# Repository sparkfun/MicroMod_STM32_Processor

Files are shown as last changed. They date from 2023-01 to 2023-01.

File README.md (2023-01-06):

SparkFun STM32 MicroMod Processor
========================================

SparkFun STM32 MicroMod Processor

[*SparkFun STM32 MicroMod Processor v20 (21326)*](https://www.sparkfun.com/products/21326)

We've brought the power and precision of the STM32 Processor to the [SparkFun MicroMod ecosystem](https://www.sparkfun.com/micromod)! Please welcome the [MicroMod STM32 Processor Board](https://www.sparkfun.com/products/21326)! With the high-performance Arm® Cortex®-M4 32-bit RISC core, Flash memory up to 1 Mbyte, up to 192 Kbytes of SRAM, a memory protection unit (MPU), high-speed embedded memories, up to 4 Kbytes of backup SRAM, and an extensive range of enhanced I/Os and peripherals, this board is chock full of functionality. 

Repository Contents
-------------------

* **/Hardware** - Eagle design files (.brd, .sch)
* **/Production** - Production panel files (.brd)

Documentation
--------------
* **[Hookup Guide](https://learn.sparkfun.com/tutorials/micromod-stm32-processor-hookup-guide)** - Basic hookup guide for the MicroMod STM32 Processor Board.
* **[Getting Started with MicroMod](https://learn.sparkfun.com/tutorials/getting-started-with-micromod)** - A tutorial to help you get started with the MicroMod Ecosystem. 
* **[Designing with MicroMod](https://learn.sparkfun.com/tutorials/designing-with-micromod)** - A tutorial to walk you through the specs of the MicroMod processor and carrier board as well as the basics of incorporating the MicroMod form factor into your own PCB designs.

License Information
-------------------

This product is _**open source**_! 

Please review the LICENSE.md file for license information. 

If you have any questions or concerns on licensing, please contact technical support on our [SparkFun forums](https://forum.sparkfun.com/viewforum.php?f=152).

Distributed as-is; no warranty is given.

- Your friends at SparkFun.

_<COLLABORATION CREDIT>_

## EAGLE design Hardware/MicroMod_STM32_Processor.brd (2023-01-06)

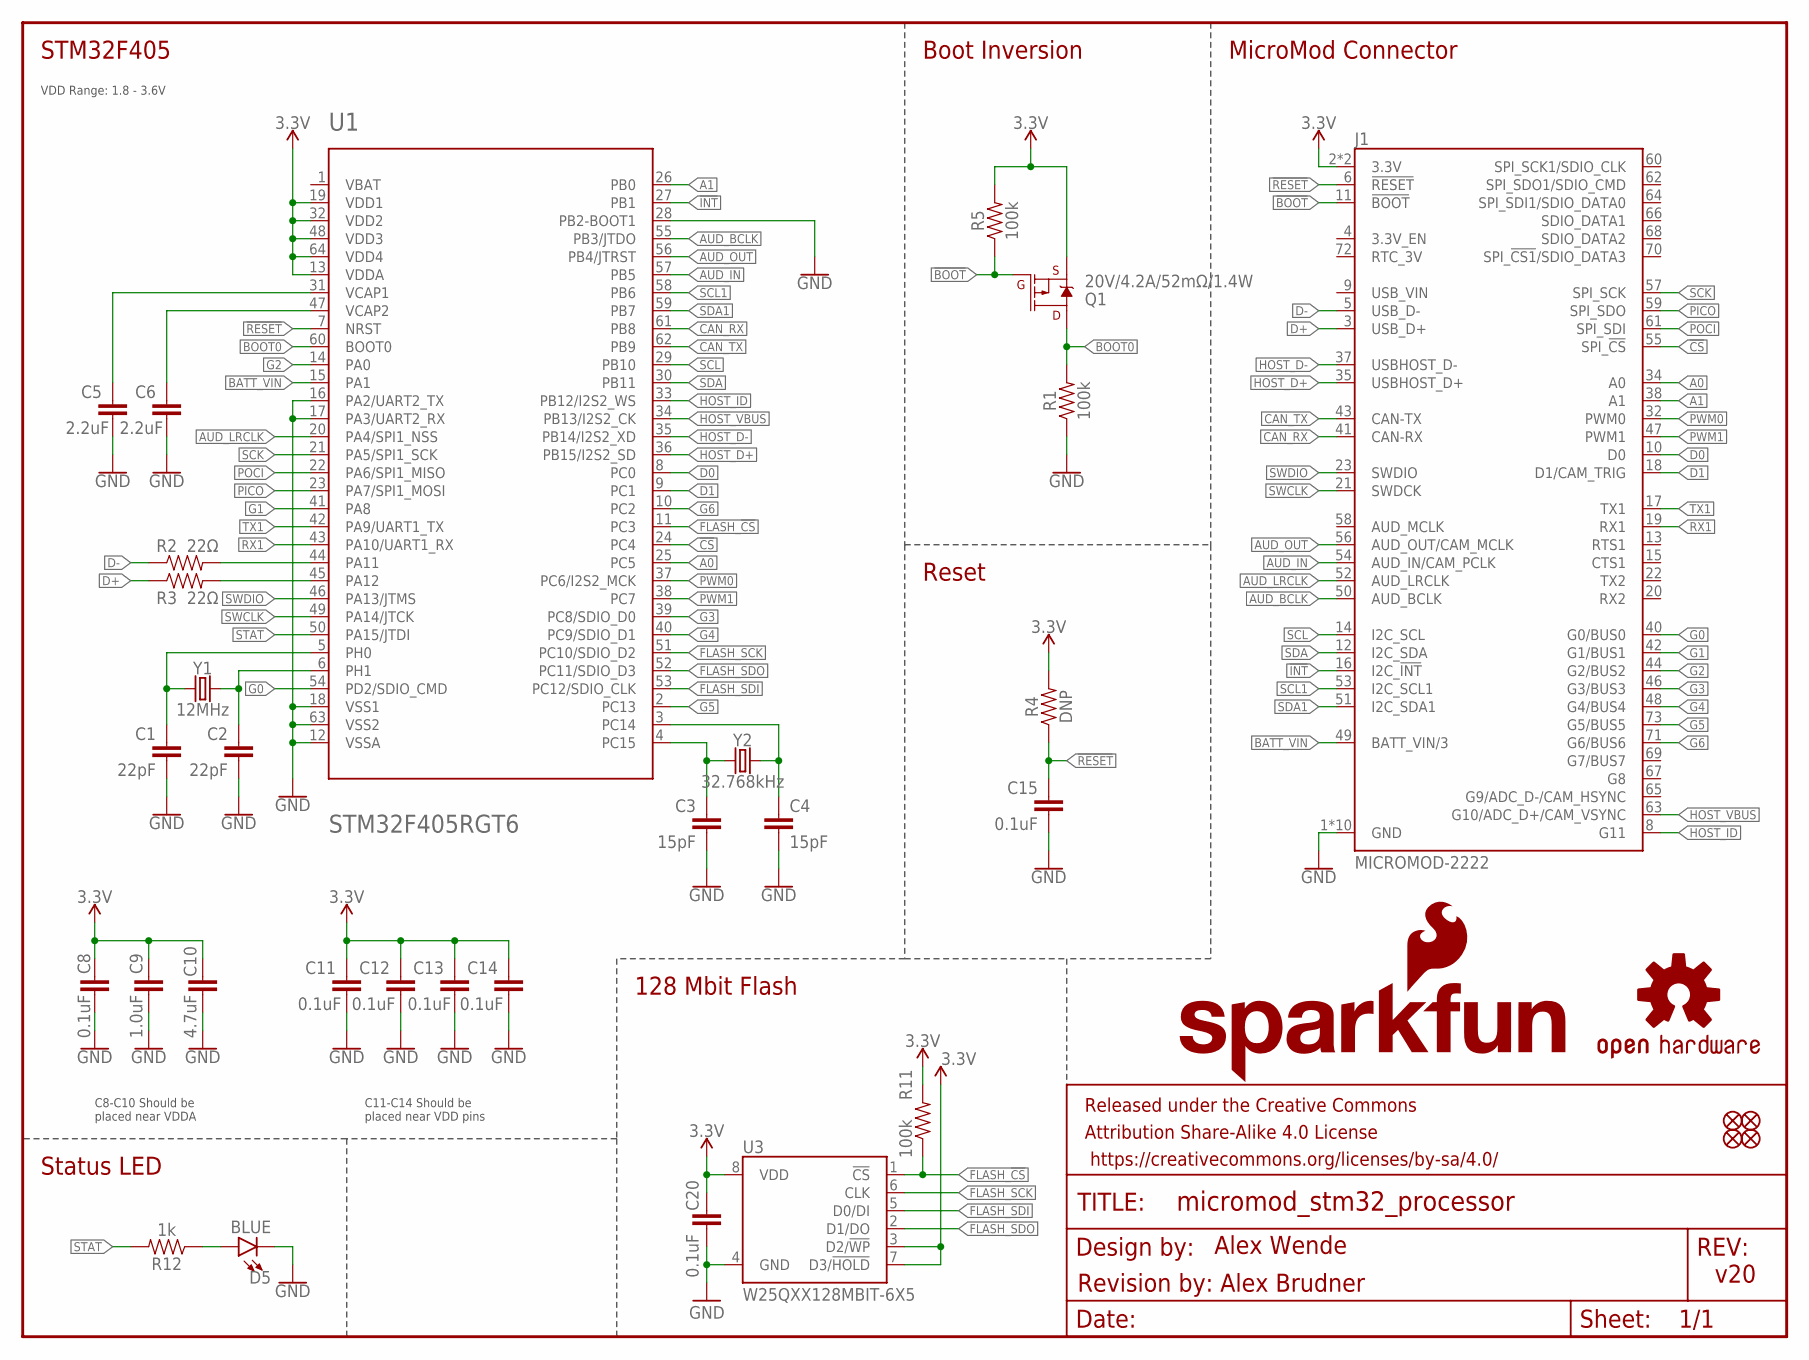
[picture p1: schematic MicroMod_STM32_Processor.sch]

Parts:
C1, C2: 22pF; 0402-TIGHT
C3, C4: 15pF; 0402-TIGHT
C5, C6: 2.2uF; 0402-TIGHT
C8, C11, C12, C13, C14, C15, C20: 0.1uF; 0402-TIGHT
C9: 1.0uF; 0402-TIGHT
C10: 4.7uF; 0402-TIGHT
D5: BLUE; LED-0603
FD1, FD2, FD3, FD4: FIDUCIALUFIDUCIAL; FIDUCIAL-MICRO
FRAME1: FRAME-LETTER; CREATIVE_COMMONS
J1: MICROMOD-2222; M.2-CARD-E-22
LOGO2: OSHW-LOGOS; OSHW-LOGO-S
LOGO3: SFE_LOGO_NAME_FLAME.1_INCH; SFE_LOGO_NAME_FLAME_.1
Q1: 20V/4.2A/52mΩ/1.4W; SOT23-3
R1, R5, R11: 100k; 0402-TIGHT
R2, R3: 22Ω; 0402-TIGHT
R4: DNP; 0402-TIGHT_NO_CREAM
R12: 1k; 0402-TIGHT
U1: STM32F405RGT6; TQFP64
U3: W25QXX128MBIT-6X5; WSON-8-6X5
Y1: 12MHz; CRYSTAL-SMD-5X3.2-4PAD
Y2: 32.768kHz; CRYSTAL-SMD-3.2X1.5MM

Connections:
3.3V: C8.1, C9.1, C10.1, C11.1, C12.1, C13.1, C14.1, C20.1, J1.2 (3.3V), J1.74 (3.3V), Q1.2 (S), R4.2, R5.2, R11.2, U1.13 (VDDA), U1.19 (VDD1), U1.32 (VDD2), U1.48 (VDD3), U1.64 (VDD4), U3.3 (D2/!WP!), U3.7 (D3/!HOLD!), U3.8 (VDD)
!BOOT: J1.11 (!BOOT!), Q1.1 (G), R5.1
!CS: J1.55 (SPI_!CS!), U1.24 (PC4)
!INT: J1.16 (I2C_!INT!), U1.27 (PB1)
!RESET: C15.1, J1.6 (!RESET!), R4.1, U1.7 (NRST)
A0: J1.34 (A0), U1.25 (PC5)
A1: J1.38 (A1), U1.26 (PB0)
AUD_BCLK: J1.50 (AUD_BCLK), U1.55 (PB3/JTDO)
AUD_IN: J1.54 (AUD_IN/CAM_PCLK), U1.57 (PB5)
AUD_LRCLK: J1.52 (AUD_LRCLK), U1.20 (PA4/SPI1_NSS)
AUD_OUT: J1.56 (AUD_OUT/CAM_MCLK), U1.56 (PB4/JTRST)
BATT_VIN: J1.49 (BATT_VIN/3), U1.15 (PA1)
BOOT0: Q1.3 (D), R1.2, U1.60 (BOOT0)
CAN_RX: J1.41 (CAN-RX), U1.61 (PB8)
CAN_TX: J1.43 (CAN-TX), U1.62 (PB9)
D0: J1.10 (D0), U1.8 (PC0)
D1: J1.18 (D1/CAM_TRIG), U1.9 (PC1)
D+: J1.3 (USB_D+), R3.1
D-: J1.5 (USB_D-), R2.1
FLASH_!CS: R11.1, U1.11 (PC3), U3.1 (!CS!)
FLASH_SCK: U1.51 (PC10/SDIO_D2), U3.6 (CLK)
FLASH_SDI: U1.53 (PC12/SDIO_CLK), U3.5 (D0/DI)
FLASH_SDO: U1.52 (PC11/SDIO_D3), U3.2 (D1/DO)
G0: J1.40 (G0/BUS0), U1.54 (PD2/SDIO_CMD)
G1: J1.42 (G1/BUS1), U1.41 (PA8)
G2: J1.44 (G2/BUS2), U1.14 (PA0)
G3: J1.46 (G3/BUS3), U1.39 (PC8/SDIO_D0)
G4: J1.48 (G4/BUS4), U1.40 (PC9/SDIO_D1)
G5: J1.73 (G5/BUS5), U1.2 (PC13)
G6: J1.71 (G6/BUS6), U1.10 (PC2)
GND: C1.2, C2.2, C3.2, C4.2, C5.2, C6.2, C8.2, C9.2, C10.2, C11.2, C12.2, C13.2, C14.2, C15.2, C20.2, D5.C, J1.1 (GND), J1.7 (GND), J1.33 (GND), J1.36 (GND), J1.39 (GND), J1.45 (GND), J1.75 (GND), J1.GND1 (GND), J1.GND2 (GND), J1.GND3 (GND), R1.1, U1.12 (VSSA), U1.16 (PA2/UART2_TX), U1.17 (PA3/UART2_RX), U1.18 (VSS1), U1.28 (PB2-BOOT1), U1.63 (VSS2), U3.4 (GND)
HOST_D+: J1.35 (USBHOST_D+), U1.36 (PB15/I2S2_SD)
HOST_D-: J1.37 (USBHOST_D-), U1.35 (PB14/I2S2_XD)
HOST_ID: J1.8 (G11), U1.33 (PB12/I2S2_WS)
HOST_VBUS: J1.63 (G10/ADC_D+/CAM_VSYNC), U1.34 (PB13/I2S2_CK)
unnamed: D5.A, R12.1
unnamed: R2.2, U1.44 (PA11)
unnamed: R3.2, U1.45 (PA12)
unnamed: C4.1, U1.3 (PC14), Y2.P$2 (2)
unnamed: C3.1, U1.4 (PC15), Y2.P$1 (1)
unnamed: C2.1, U1.6 (PH1), Y1.3 (2)
unnamed: C1.1, U1.5 (PH0), Y1.1
unnamed: C6.1, U1.47 (VCAP2)
unnamed: C5.1, U1.31 (VCAP1)
PICO: J1.59 (SPI_SDO), U1.23 (PA7/SPI1_MOSI)
POCI: J1.61 (SPI_SDI), U1.22 (PA6/SPI1_MISO)
PWM0: J1.32 (PWM0), U1.37 (PC6/I2S2_MCK)
PWM1: J1.47 (PWM1), U1.38 (PC7)
RX1: J1.19 (RX1), U1.43 (PA10/UART1_RX)
SCK: J1.57 (SPI_SCK), U1.21 (PA5/SPI1_SCK)
SCL: J1.14 (I2C_SCL), U1.29 (PB10)
SCL1: J1.53 (I2C_SCL1), U1.58 (PB6)
SDA: J1.12 (I2C_SDA), U1.30 (PB11)
SDA1: J1.51 (I2C_SDA1), U1.59 (PB7)
STAT: R12.2, U1.50 (PA15/JTDI)
SWCLK: J1.21 (SWDCK), U1.49 (PA14/JTCK)
SWDIO: J1.23 (SWDIO), U1.46 (PA13/JTMS)
TX1: J1.17 (TX1), U1.42 (PA9/UART1_TX)

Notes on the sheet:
128 Mbit Flash
Status LED
C11-C14 Should be placed near VDD pins
C8-C10 Should be placed near VDDA
Boot Inversion
Reset
MicroMod Connector
STM32F405
v20
Alex Wende
VDD Range: 1.8 - 3.6V
Revision by: Alex Brudner

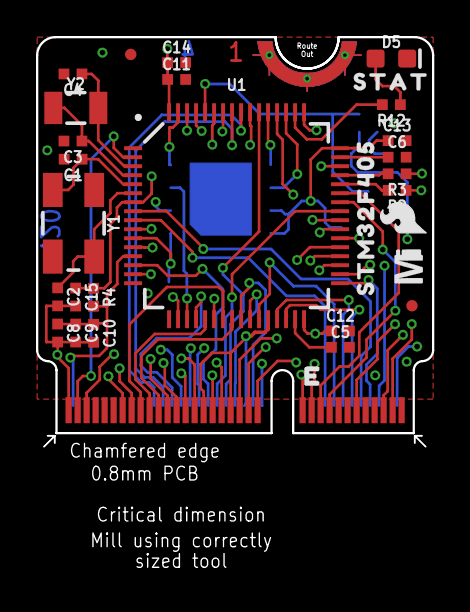
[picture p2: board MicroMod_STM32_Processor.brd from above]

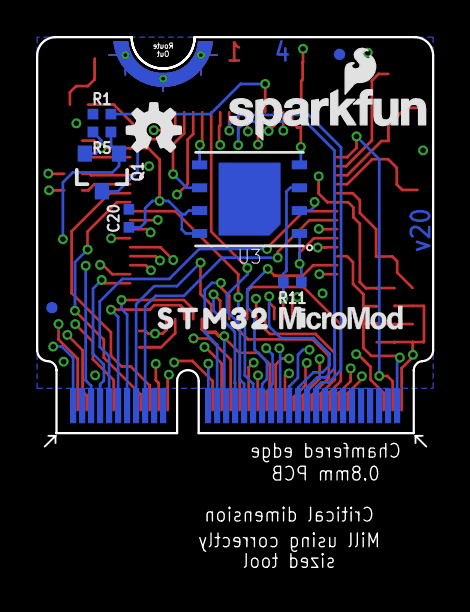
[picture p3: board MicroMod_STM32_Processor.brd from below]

Board: 4 copper layers, 22.0 x 22.8 mm, 43 parts (12 on the bottom side), 58 nets.

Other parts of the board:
U$1: STAT0
U$2: STM320
U$3: MICROMOD_MI_LOGO_.35
U$4: STM32F4050
U$5: MICROMOD_LOGO_.3
U$6: SFE_LOGO_FLAME_.1
U$7: PRODUCTION_INSTRUCTIONS

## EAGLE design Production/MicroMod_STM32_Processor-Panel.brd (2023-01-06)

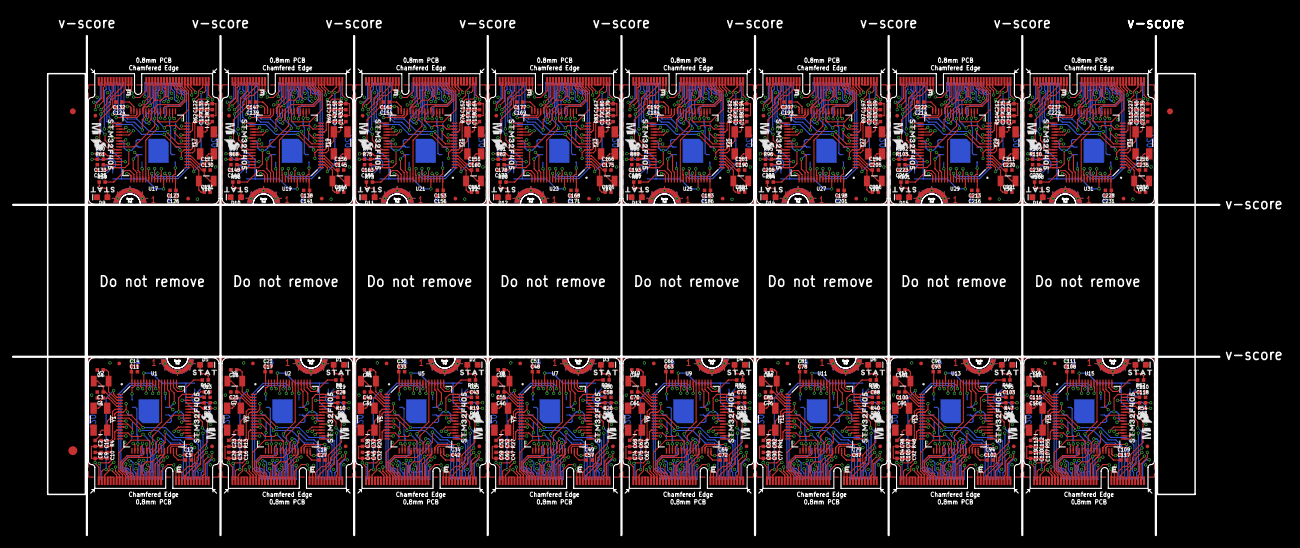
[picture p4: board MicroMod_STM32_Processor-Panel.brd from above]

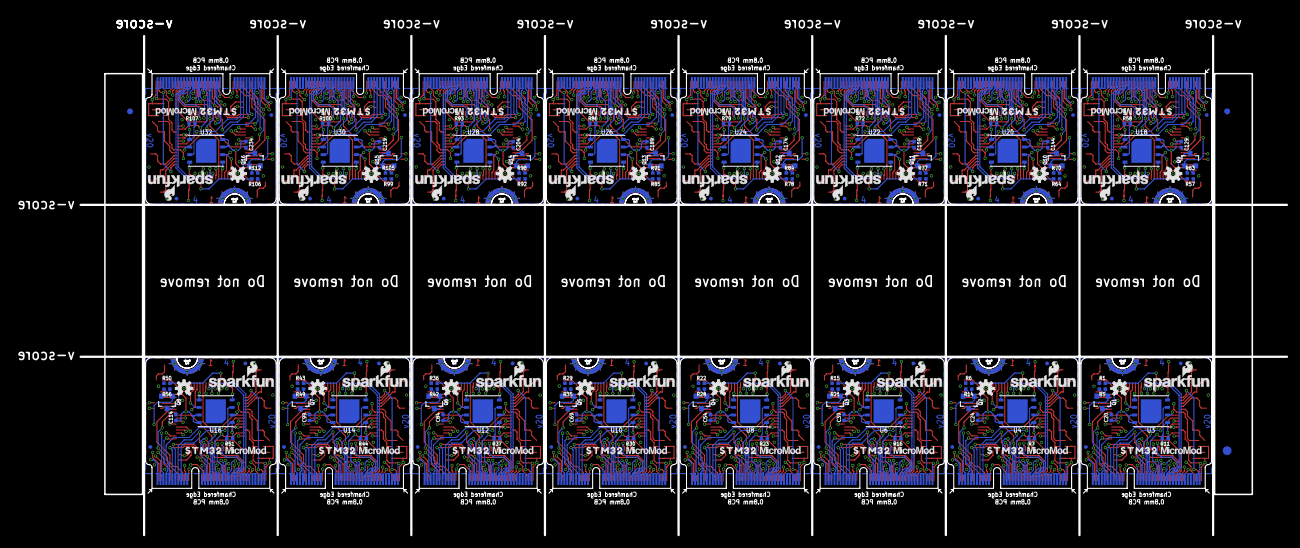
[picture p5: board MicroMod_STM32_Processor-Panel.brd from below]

Board: 4 copper layers, 203.2 x 84.1 mm, 662 parts (195 on the bottom side), 928 nets.

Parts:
C1, C2, C7, C23, C31, C38, C46, C53, C61, C68, C76, C83, C91, C98, C106, C113, C121, C128, C136, C143, C151, C158, C166, C173, C181, C188, C196, C203, C211, C218, C226, C233: 22pF; 0402-TIGHT
C3, C4, C25, C26, C40, C41, C55, C56, C70, C71, C85, C86, C100, C101, C115, C116, C130, C131, C145, C146, C160, C161, C175, C176, C190, C191, C205, C206, C220, C221, C235, C236: 15pF; 0402-TIGHT
C5, C6, C27, C28, C42, C43, C57, C58, C72, C73, C87, C88, C102, C103, C117, C118, C132, C133, C147, C148, C162, C163, C177, C178, C192, C193, C207, C208, C222, C223, C237, C238: 2.2uF; 0402-TIGHT
C8, C11, C12, C13, C14, C15, C17, C18, C19, C20, C21, C22, C24, C29, C33, C34, C35, C36, C37, C39, C44, C48, C49, C50, C51, C52, C54, C59, C63, C64, C65, C66, C67, C69, C74, C78, C79, C80, C81, C82, C84, C89, C93, C94, C95, C96, C97, C99, C104, C108, C109, C110, C111, C112, C114, C119, C123, C124, C125, C126, C127, C129, C134, C138, C139, C140, C141, C142, C144, C149, C153, C154, C155, C156, C157, C159, C164, C168, C169, C170, C171, C172, C174, C179, C183, C184, C185, C186, C187, C189, C194, C198, C199, C200, C201, C202, C204, C209, C213, C214, C215, C216, C217, C219, C224, C228, C229, C230, C231, C232, C234, C239: 0.1uF; 0402-TIGHT
C9, C30, C45, C60, C75, C90, C105, C120, C135, C150, C165, C180, C195, C210, C225, C240: 1.0uF; 0402-TIGHT
C10, C16, C32, C47, C62, C77, C92, C107, C122, C137, C152, C167, C182, C197, C212, C227: 4.7uF; 0402-TIGHT
D1, D2, D3, D4, D5, D6, D7, D8, D9, D10, D11, D12, D13, D14, D15, D16: BLUE; LED-0603
E$1, E$2, E$3, E$4: FIDUCIAL-1X2
E$5, E$6: FIDUCIAL-1.5X3
FD1, FD2, FD3, FD4, FD5, FD6, FD7, FD8, FD9, FD10, FD11, FD12, FD13, FD14, FD15, FD16, FD17, FD18, FD19, FD20, FD21, FD22, FD23, FD24, FD25, FD26, FD27, FD28, FD29, FD30, FD31, FD32, FD33, FD34, FD35, FD36, FD37, FD38, FD39, FD40, FD41, FD42, FD43, FD44, FD45, FD46, FD47, FD48, FD49, FD50, FD51, FD52, FD53, FD54, FD55, FD56, FD57, FD58, FD59, FD60, FD61, FD62, FD63, FD64: FIDUCIALUFIDUCIAL; FIDUCIAL-MICRO
J1, J2, J3, J4, J5, J6, J7, J8, J9, J10, J11, J12, J13, J14, J15, J16: MICROMOD-2222; M.2-CARD-E-22
LOGO1, LOGO2, LOGO5, LOGO7, LOGO9, LOGO11, LOGO13, LOGO15, LOGO17, LOGO19, LOGO21, LOGO23, LOGO25, LOGO27, LOGO29, LOGO31: OSHW-LOGOS; OSHW-LOGO-S
LOGO3, LOGO4, LOGO6, LOGO8, LOGO10, LOGO12, LOGO14, LOGO16, LOGO18, LOGO20, LOGO22, LOGO24, LOGO26, LOGO28, LOGO30, LOGO32: SFE_LOGO_NAME_FLAME.1_INCH; SFE_LOGO_NAME_FLAME_.1
Q1, Q2, Q3, Q4, Q5, Q6, Q7, Q8, Q9, Q10, Q11, Q12, Q13, Q14, Q15, Q16: SOT23-3
R1, R5, R6, R7, R11, R14, R15, R16, R21, R22, R23, R28, R29, R30, R35, R36, R37, R42, R43, R44, R49, R50, R51, R56, R57, R58, R63, R64, R65, R70, R71, R72, R77, R78, R79, R84, R85, R86, R91, R92, R93, R98, R99, R100, R105, R106, R107, R112: 100k; 0402-TIGHT
R2, R3, R9, R10, R18, R19, R25, R26, R32, R33, R39, R40, R46, R47, R53, R54, R60, R61, R67, R68, R74, R75, R81, R82, R88, R89, R95, R96, R102, R103, R109, R110: 22; 0402-TIGHT
R4, R13, R20, R27, R34, R41, R48, R55, R62, R69, R76, R83, R90, R97, R104, R111: 5.1k; 0402-TIGHT
R8, R12, R17, R24, R31, R38, R45, R52, R59, R66, R73, R80, R87, R94, R101, R108: 1k; 0402-TIGHT
U1, U2, U5, U7, U9, U11, U13, U15, U17, U19, U21, U23, U25, U27, U29, U31: STM32F405RGT6; TQFP64
U3, U4, U6, U8, U10, U12, U14, U16, U18, U20, U22, U24, U26, U28, U30, U32: W25QXX128MBIT-6X5; WSON-8-6X5
U$1, U$7, U$13, U$19, U$25, U$31, U$37, U$43, U$49, U$55, U$61, U$67, U$73, U$79, U$85, U$91: STAT0
U$2, U$8, U$14, U$20, U$26, U$32, U$38, U$44, U$50, U$56, U$62, U$68, U$74, U$80, U$86, U$92: STM320
U$3, U$9, U$15, U$21, U$27, U$33, U$39, U$45, U$51, U$57, U$63, U$69, U$75, U$81, U$87, U$93: MICROMOD_MI_LOGO_.35
U$4, U$10, U$16, U$22, U$28, U$34, U$40, U$46, U$52, U$58, U$64, U$70, U$76, U$82, U$88, U$94: STM32F4050
U$5, U$11, U$17, U$23, U$29, U$35, U$41, U$47, U$53, U$59, U$65, U$71, U$77, U$83, U$89, U$95: MICROMOD_LOGO_.3
U$6, U$12, U$18, U$24, U$30, U$36, U$42, U$48, U$54, U$60, U$66, U$72, U$78, U$84, U$90, U$96: SFE_LOGO_FLAME_.1
Y1, Y3, Y5, Y7, Y9, Y11, Y13, Y15, Y17, Y19, Y21, Y23, Y25, Y27, Y29, Y31: 12MHz; CRYSTAL-SMD-5X3.2-4PAD
Y2, Y4, Y6, Y8, Y10, Y12, Y14, Y16, Y18, Y20, Y22, Y24, Y26, Y28, Y30, Y32: 32.768kHz; CRYSTAL-SMD-3.2X1.5MM

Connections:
3.3V: C8.1, C9.1, C10.1, C11.1, C12.1, C13.1, C14.1, C20.1, J1.2, J1.74, Q1.2, R4.2, R5.2, R11.2, U1.13, U1.19, U1.32, U1.48, U1.64, U3.3, U3.7, U3.8
3.3V1: C16.1, C17.1, C18.1, C19.1, C21.1, C24.1, C29.1, C30.1, J2.2, J2.74, Q2.2, R7.2, R13.2, R14.2, U2.13, U2.19, U2.32, U2.48, U2.64, U4.3, U4.7, U4.8
3.3V2: C32.1, C33.1, C34.1, C35.1, C36.1, C39.1, C44.1, C45.1, J3.2, J3.74, Q3.2, R16.2, R20.2, R21.2, U5.13, U5.19, U5.32, U5.48, U5.64, U6.3, U6.7, U6.8
3.3V3: C47.1, C48.1, C49.1, C50.1, C51.1, C54.1, C59.1, C60.1, J4.2, J4.74, Q4.2, R23.2, R27.2, R28.2, U7.13, U7.19, U7.32, U7.48, U7.64, U8.3, U8.7, U8.8
3.3V4: C62.1, C63.1, C64.1, C65.1, C66.1, C69.1, C74.1, C75.1, J5.2, J5.74, Q5.2, R30.2, R34.2, R35.2, U9.13, U9.19, U9.32, U9.48, U9.64, U10.3, U10.7, U10.8
3.3V5: C77.1, C78.1, C79.1, C80.1, C81.1, C84.1, C89.1, C90.1, J6.2, J6.74, Q6.2, R37.2, R41.2, R42.2, U11.13, U11.19, U11.32, U11.48, U11.64, U12.3, U12.7, U12.8
3.3V6: C92.1, C93.1, C94.1, C95.1, C96.1, C99.1, C104.1, C105.1, J7.2, J7.74, Q7.2, R44.2, R48.2, R49.2, U13.13, U13.19, U13.32, U13.48, U13.64, U14.3, U14.7, U14.8
3.3V7: C107.1, C108.1, C109.1, C110.1, C111.1, C114.1, C119.1, C120.1, J8.2, J8.74, Q8.2, R51.2, R55.2, R56.2, U15.13, U15.19, U15.32, U15.48, U15.64, U16.3, U16.7, U16.8
3.3V8: C122.1, C123.1, C124.1, C125.1, C126.1, C129.1, C134.1, C135.1, J9.2, J9.74, Q9.2, R58.2, R62.2, R63.2, U17.13, U17.19, U17.32, U17.48, U17.64, U18.3, U18.7, U18.8
3.3V9: C137.1, C138.1, C139.1, C140.1, C141.1, C144.1, C149.1, C150.1, J10.2, J10.74, Q10.2, R65.2, R69.2, R70.2, U19.13, U19.19, U19.32, U19.48, U19.64, U20.3, U20.7, U20.8
3.3V10: C152.1, C153.1, C154.1, C155.1, C156.1, C159.1, C164.1, C165.1, J11.2, J11.74, Q11.2, R72.2, R76.2, R77.2, U21.13, U21.19, U21.32, U21.48, U21.64, U22.3, U22.7, U22.8
3.3V11: C167.1, C168.1, C169.1, C170.1, C171.1, C174.1, C179.1, C180.1, J12.2, J12.74, Q12.2, R79.2, R83.2, R84.2, U23.13, U23.19, U23.32, U23.48, U23.64, U24.3, U24.7, U24.8
3.3V12: C182.1, C183.1, C184.1, C185.1, C186.1, C189.1, C194.1, C195.1, J13.2, J13.74, Q13.2, R86.2, R90.2, R91.2, U25.13, U25.19, U25.32, U25.48, U25.64, U26.3, U26.7, U26.8
3.3V13: C197.1, C198.1, C199.1, C200.1, C201.1, C204.1, C209.1, C210.1, J14.2, J14.74, Q14.2, R93.2, R97.2, R98.2, U27.13, U27.19, U27.32, U27.48, U27.64, U28.3, U28.7, U28.8
3.3V14: C212.1, C213.1, C214.1, C215.1, C216.1, C219.1, C224.1, C225.1, J15.2, J15.74, Q15.2, R100.2, R104.2, R105.2, U29.13, U29.19, U29.32, U29.48, U29.64, U30.3, U30.7, U30.8
3.3V15: C227.1, C228.1, C229.1, C230.1, C231.1, C234.1, C239.1, C240.1, J16.2, J16.74, Q16.2, R107.2, R111.2, R112.2, U31.13, U31.19, U31.32, U31.48, U31.64, U32.3, U32.7, U32.8
!BOOT: J1.11, Q1.1, R5.1
!BOOT1: J2.11, Q2.1, R14.1
!BOOT2: J3.11, Q3.1, R21.1
!BOOT3: J4.11, Q4.1, R28.1
!BOOT4: J5.11, Q5.1, R35.1
!BOOT5: J6.11, Q6.1, R42.1
!BOOT6: J7.11, Q7.1, R49.1
!BOOT7: J8.11, Q8.1, R56.1
!BOOT8: J9.11, Q9.1, R63.1
!BOOT9: J10.11, Q10.1, R70.1
!BOOT10: J11.11, Q11.1, R77.1
!BOOT11: J12.11, Q12.1, R84.1
!BOOT12: J13.11, Q13.1, R91.1
!BOOT13: J14.11, Q14.1, R98.1
!BOOT14: J15.11, Q15.1, R105.1
!BOOT15: J16.11, Q16.1, R112.1
!CS: J1.55, U1.24
!CS1: J2.55, U2.24
!CS2: J3.55, U5.24
!CS3: J4.55, U7.24
!CS4: J5.55, U9.24
!CS5: J6.55, U11.24
!CS6: J7.55, U13.24
!CS7: J8.55, U15.24
!CS8: J9.55, U17.24
!CS9: J10.55, U19.24
!CS10: J11.55, U21.24
!CS11: J12.55, U23.24
!CS12: J13.55, U25.24
!CS13: J14.55, U27.24
!CS14: J15.55, U29.24
!CS15: J16.55, U31.24
!INT: J1.16, U1.27
!INT1: J2.16, U2.27
!INT2: J3.16, U5.27
!INT3: J4.16, U7.27
!INT4: J5.16, U9.27
!INT5: J6.16, U11.27
!INT6: J7.16, U13.27
!INT7: J8.16, U15.27
!INT8: J9.16, U17.27
!INT9: J10.16, U19.27
!INT10: J11.16, U21.27
!INT11: J12.16, U23.27
!INT12: J13.16, U25.27
!INT13: J14.16, U27.27
!INT14: J15.16, U29.27
!INT15: J16.16, U31.27
!RESET: C15.1, J1.6, R4.1, U1.7
!RESET1: C22.1, J2.6, R13.1, U2.7
!RESET2: C37.1, J3.6, R20.1, U5.7
!RESET3: C52.1, J4.6, R27.1, U7.7
!RESET4: C67.1, J5.6, R34.1, U9.7
!RESET5: C82.1, J6.6, R41.1, U11.7
!RESET6: C97.1, J7.6, R48.1, U13.7
!RESET7: C112.1, J8.6, R55.1, U15.7
!RESET8: C127.1, J9.6, R62.1, U17.7
!RESET9: C142.1, J10.6, R69.1, U19.7
!RESET10: C157.1, J11.6, R76.1, U21.7
!RESET11: C172.1, J12.6, R83.1, U23.7
!RESET12: C187.1, J13.6, R90.1, U25.7
!RESET13: C202.1, J14.6, R97.1, U27.7
!RESET14: C217.1, J15.6, R104.1, U29.7
!RESET15: C232.1, J16.6, R111.1, U31.7
A0: J1.34, U1.25
A1: J1.38, U1.26
A2: J2.34, U2.25
A3: J2.38, U2.26
A4: J3.34, U5.25
A5: J3.38, U5.26
A6: J4.34, U7.25
A7: J4.38, U7.26
A8: J5.34, U9.25
A9: J5.38, U9.26
A10: J6.34, U11.25
A11: J6.38, U11.26
A12: J7.34, U13.25
A13: J7.38, U13.26
A14: J8.34, U15.25
A15: J8.38, U15.26
A16: J9.34, U17.25
A17: J9.38, U17.26
A18: J10.34, U19.25
A19: J10.38, U19.26
A20: J11.34, U21.25
A21: J11.38, U21.26
A22: J12.34, U23.25
A23: J12.38, U23.26
A24: J13.34, U25.25
A25: J13.38, U25.26
A26: J14.34, U27.25
A27: J14.38, U27.26
A28: J15.34, U29.25
A29: J15.38, U29.26
A30: J16.34, U31.25
A31: J16.38, U31.26
AUD_BCLK: J1.50, U1.55
AUD_BCLK1: J2.50, U2.55
AUD_BCLK2: J3.50, U5.55
AUD_BCLK3: J4.50, U7.55
AUD_BCLK4: J5.50, U9.55
AUD_BCLK5: J6.50, U11.55
AUD_BCLK6: J7.50, U13.55
AUD_BCLK7: J8.50, U15.55
AUD_BCLK8: J9.50, U17.55
AUD_BCLK9: J10.50, U19.55
AUD_BCLK10: J11.50, U21.55
AUD_BCLK11: J12.50, U23.55
AUD_BCLK12: J13.50, U25.55
AUD_BCLK13: J14.50, U27.55
AUD_BCLK14: J15.50, U29.55
AUD_BCLK15: J16.50, U31.55
AUD_IN: J1.54, U1.57
AUD_IN1: J2.54, U2.57
AUD_IN2: J3.54, U5.57
AUD_IN3: J4.54, U7.57
AUD_IN4: J5.54, U9.57
AUD_IN5: J6.54, U11.57
AUD_IN6: J7.54, U13.57
AUD_IN7: J8.54, U15.57
AUD_IN8: J9.54, U17.57
AUD_IN9: J10.54, U19.57
AUD_IN10: J11.54, U21.57
AUD_IN11: J12.54, U23.57
AUD_IN12: J13.54, U25.57
AUD_IN13: J14.54, U27.57
AUD_IN14: J15.54, U29.57
AUD_IN15: J16.54, U31.57
AUD_LRCLK: J1.52, U1.20
AUD_LRCLK1: J2.52, U2.20
AUD_LRCLK2: J3.52, U5.20
AUD_LRCLK3: J4.52, U7.20
AUD_LRCLK4: J5.52, U9.20
AUD_LRCLK5: J6.52, U11.20
AUD_LRCLK6: J7.52, U13.20
AUD_LRCLK7: J8.52, U15.20
AUD_LRCLK8: J9.52, U17.20
AUD_LRCLK9: J10.52, U19.20
AUD_LRCLK10: J11.52, U21.20
AUD_LRCLK11: J12.52, U23.20
AUD_LRCLK12: J13.52, U25.20
AUD_LRCLK13: J14.52, U27.20
AUD_LRCLK14: J15.52, U29.20
AUD_LRCLK15: J16.52, U31.20
AUD_OUT: J1.56, U1.56
AUD_OUT1: J2.56, U2.56
AUD_OUT2: J3.56, U5.56
AUD_OUT3: J4.56, U7.56
AUD_OUT4: J5.56, U9.56
AUD_OUT5: J6.56, U11.56
AUD_OUT6: J7.56, U13.56
AUD_OUT7: J8.56, U15.56
AUD_OUT8: J9.56, U17.56
AUD_OUT9: J10.56, U19.56
AUD_OUT10: J11.56, U21.56
AUD_OUT11: J12.56, U23.56
AUD_OUT12: J13.56, U25.56
AUD_OUT13: J14.56, U27.56
AUD_OUT14: J15.56, U29.56
AUD_OUT15: J16.56, U31.56
BATT_VIN: J1.49, U1.15
BATT_VIN1: J2.49, U2.15
BATT_VIN2: J3.49, U5.15
BATT_VIN3: J4.49, U7.15
BATT_VIN4: J5.49, U9.15
BATT_VIN5: J6.49, U11.15
BATT_VIN6: J7.49, U13.15
BATT_VIN7: J8.49, U15.15
BATT_VIN8: J9.49, U17.15
BATT_VIN9: J10.49, U19.15
BATT_VIN10: J11.49, U21.15
BATT_VIN11: J12.49, U23.15
BATT_VIN12: J13.49, U25.15
BATT_VIN13: J14.49, U27.15
BATT_VIN14: J15.49, U29.15
BATT_VIN15: J16.49, U31.15
BOOT0: Q1.3, R1.2, U1.60
BOOT1: Q2.3, R6.2, U2.60
BOOT2: Q3.3, R15.2, U5.60
BOOT3: Q4.3, R22.2, U7.60
BOOT4: Q5.3, R29.2, U9.60
BOOT5: Q6.3, R36.2, U11.60
BOOT6: Q7.3, R43.2, U13.60
BOOT7: Q8.3, R50.2, U15.60
BOOT8: Q9.3, R57.2, U17.60
BOOT9: Q10.3, R64.2, U19.60
BOOT10: Q11.3, R71.2, U21.60
BOOT11: Q12.3, R78.2, U23.60
BOOT12: Q13.3, R85.2, U25.60
BOOT13: Q14.3, R92.2, U27.60
BOOT14: Q15.3, R99.2, U29.60
BOOT15: Q16.3, R106.2, U31.60
CAN_RX: J1.41, U1.61
CAN_RX1: J2.41, U2.61
CAN_RX2: J3.41, U5.61
CAN_RX3: J4.41, U7.61
CAN_RX4: J5.41, U9.61
CAN_RX5: J6.41, U11.61
CAN_RX6: J7.41, U13.61
CAN_RX7: J8.41, U15.61
CAN_RX8: J9.41, U17.61
CAN_RX9: J10.41, U19.61
CAN_RX10: J11.41, U21.61
CAN_RX11: J12.41, U23.61
CAN_RX12: J13.41, U25.61
CAN_RX13: J14.41, U27.61
CAN_RX14: J15.41, U29.61
CAN_RX15: J16.41, U31.61
CAN_TX: J1.43, U1.62
CAN_TX1: J2.43, U2.62
CAN_TX2: J3.43, U5.62
CAN_TX3: J4.43, U7.62
CAN_TX4: J5.43, U9.62
CAN_TX5: J6.43, U11.62
CAN_TX6: J7.43, U13.62
CAN_TX7: J8.43, U15.62
CAN_TX8: J9.43, U17.62
CAN_TX9: J10.43, U19.62
CAN_TX10: J11.43, U21.62
CAN_TX11: J12.43, U23.62
CAN_TX12: J13.43, U25.62
CAN_TX13: J14.43, U27.62
CAN_TX14: J15.43, U29.62
CAN_TX15: J16.43, U31.62
D0: J1.10, U1.8
D1: J1.18, U1.9
D2: J2.10, U2.8
D3: J2.18, U2.9
D4: J3.10, U5.8
D5: J3.18, U5.9
D6: J4.10, U7.8
D7: J4.18, U7.9
D8: J5.10, U9.8
D9: J5.18, U9.9
D10: J6.10, U11.8
D11: J6.18, U11.9
D12: J7.10, U13.8
D13: J7.18, U13.9
D14: J8.10, U15.8
D15: J8.18, U15.9
D16: J9.10, U17.8
D17: J9.18, U17.9
D18: J10.10, U19.8
D19: J10.18, U19.9
D20: J11.10, U21.8
D21: J11.18, U21.9
D22: J12.10, U23.8
D23: J12.18, U23.9
D24: J13.10, U25.8
D25: J13.18, U25.9
D26: J14.10, U27.8
D27: J14.18, U27.9
D28: J15.10, U29.8
D29: J15.18, U29.9
D30: J16.10, U31.8
D31: J16.18, U31.9
D+: J1.3, R3.1
D+1: J2.3, R10.1
D+2: J3.3, R19.1
D+3: J4.3, R26.1
D+4: J5.3, R33.1
D+5: J6.3, R40.1
D+6: J7.3, R47.1
D+7: J8.3, R54.1
D+8: J9.3, R61.1
D+9: J10.3, R68.1
D+10: J11.3, R75.1
D+11: J12.3, R82.1
D+12: J13.3, R89.1
D+13: J14.3, R96.1
D+14: J15.3, R103.1
D+15: J16.3, R110.1
D-: J1.5, R2.1
D-1: J2.5, R9.1
D-2: J3.5, R18.1
D-3: J4.5, R25.1
D-4: J5.5, R32.1
D-5: J6.5, R39.1
D-6: J7.5, R46.1
D-7: J8.5, R53.1
D-8: J9.5, R60.1
D-9: J10.5, R67.1
D-10: J11.5, R74.1
D-11: J12.5, R81.1
D-12: J13.5, R88.1
D-13: J14.5, R95.1
D-14: J15.5, R102.1
D-15: J16.5, R109.1
FLASH_!CS: R11.1, U1.11, U3.1
FLASH_!CS1: R7.1, U2.11, U4.1
FLASH_!CS2: R16.1, U5.11, U6.1
FLASH_!CS3: R23.1, U7.11, U8.1
FLASH_!CS4: R30.1, U9.11, U10.1
FLASH_!CS5: R37.1, U11.11, U12.1
FLASH_!CS6: R44.1, U13.11, U14.1
FLASH_!CS7: R51.1, U15.11, U16.1
FLASH_!CS8: R58.1, U17.11, U18.1
FLASH_!CS9: R65.1, U19.11, U20.1
FLASH_!CS10: R72.1, U21.11, U22.1
FLASH_!CS11: R79.1, U23.11, U24.1
FLASH_!CS12: R86.1, U25.11, U26.1
FLASH_!CS13: R93.1, U27.11, U28.1
FLASH_!CS14: R100.1, U29.11, U30.1
FLASH_!CS15: R107.1, U31.11, U32.1
FLASH_SCK: U1.51, U3.6
FLASH_SCK1: U2.51, U4.6
FLASH_SCK2: U5.51, U6.6
FLASH_SCK3: U7.51, U8.6
FLASH_SCK4: U9.51, U10.6
FLASH_SCK5: U11.51, U12.6
FLASH_SCK6: U13.51, U14.6
FLASH_SCK7: U15.51, U16.6
FLASH_SCK8: U17.51, U18.6
FLASH_SCK9: U19.51, U20.6
FLASH_SCK10: U21.51, U22.6
FLASH_SCK11: U23.51, U24.6
FLASH_SCK12: U25.51, U26.6
FLASH_SCK13: U27.51, U28.6
FLASH_SCK14: U29.51, U30.6
FLASH_SCK15: U31.51, U32.6
FLASH_SDI: U1.53, U3.5
FLASH_SDI1: U2.53, U4.5
FLASH_SDI2: U5.53, U6.5
FLASH_SDI3: U7.53, U8.5
FLASH_SDI4: U9.53, U10.5
FLASH_SDI5: U11.53, U12.5
FLASH_SDI6: U13.53, U14.5
FLASH_SDI7: U15.53, U16.5
FLASH_SDI8: U17.53, U18.5
FLASH_SDI9: U19.53, U20.5
FLASH_SDI10: U21.53, U22.5
FLASH_SDI11: U23.53, U24.5
FLASH_SDI12: U25.53, U26.5
FLASH_SDI13: U27.53, U28.5
FLASH_SDI14: U29.53, U30.5
FLASH_SDI15: U31.53, U32.5
FLASH_SDO: U1.52, U3.2
FLASH_SDO1: U2.52, U4.2
FLASH_SDO2: U5.52, U6.2
FLASH_SDO3: U7.52, U8.2
FLASH_SDO4: U9.52, U10.2
FLASH_SDO5: U11.52, U12.2
FLASH_SDO6: U13.52, U14.2
FLASH_SDO7: U15.52, U16.2
FLASH_SDO8: U17.52, U18.2
FLASH_SDO9: U19.52, U20.2
FLASH_SDO10: U21.52, U22.2
FLASH_SDO11: U23.52, U24.2
FLASH_SDO12: U25.52, U26.2
FLASH_SDO13: U27.52, U28.2
FLASH_SDO14: U29.52, U30.2
FLASH_SDO15: U31.52, U32.2
G0: J1.40, U1.54
G1: J1.42, U1.41
G2: J1.44, U1.14
G3: J1.46, U1.39
G4: J1.48, U1.40
G5: J1.73, U1.2
G6: J1.71, U1.10
G7: J2.73, U2.2
G8: J2.71, U2.10
G9: J2.46, U2.39
G10: J2.48, U2.40
G11: J2.40, U2.54
G12: J2.42, U2.41
G13: J2.44, U2.14
G14: J3.73, U5.2
G15: J3.71, U5.10
G16: J3.46, U5.39
G17: J3.48, U5.40
G18: J3.40, U5.54
G19: J3.42, U5.41
G20: J3.44, U5.14
G21: J4.73, U7.2
G22: J4.71, U7.10
G23: J4.46, U7.39
G24: J4.48, U7.40
G25: J4.40, U7.54
G26: J4.42, U7.41
G27: J4.44, U7.14
G28: J5.73, U9.2
G29: J5.71, U9.10
G30: J5.46, U9.39
G31: J5.48, U9.40
G32: J5.40, U9.54
G33: J5.42, U9.41
G34: J5.44, U9.14
G35: J6.73, U11.2
G36: J6.71, U11.10
G37: J6.46, U11.39
G38: J6.48, U11.40
G39: J6.40, U11.54
G40: J6.42, U11.41
G41: J6.44, U11.14
G42: J7.73, U13.2
G43: J7.71, U13.10
G44: J7.46, U13.39
G45: J7.48, U13.40
G46: J7.40, U13.54
G47: J7.42, U13.41
G48: J7.44, U13.14
G49: J8.73, U15.2
G50: J8.71, U15.10
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

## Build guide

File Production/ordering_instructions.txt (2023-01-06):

panel size, 194x70mm
PCB thickness, 0.8mm
number of layers, 4
bevel, Gold Fingers + 45° Finger Chamfered
soldermask color, Red
silkscreen color, White
oz copper, 1oz
finish, ENIG
stencils, none
pcs per panel, 16
min trace width, 0.1524mm / 0.0060in
min drill size, 0.2000mm / 0.0079in
filename to layer stackup 1/2/3/4: GTL, GL2, GL3, GBL

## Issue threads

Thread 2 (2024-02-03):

MICROMOD STM32 PROCESSOR AND SINGLE PAIR ETHERNET FUNCTION BOARD DON'T WORK TOGETHER

yesp-chow, 2024-02-03:
Hi there,
The hardware combination is as follows: MicroMod STM32 Processor, MicroMod Main Board, Single Pair Ethernet Function Board.
The SPE used by the library file is this: github.com/sparkfun/SparkFun_ADIN1110_Arduino_Library

After flashing the code according to the MicroMod STM32 Processor Hookup Guide, the serial port only prints the first line "Single Pair Ethernet - Example 1b Basic Echo". Then it won't continue to run.

I debugged step by step and found that the code stopped running "SparkFun_ADIN1110_Arduino_Library\src\sfe_spe_advanced.cpp ->adin1110_Init(hDevice, pCfg);"

So the board cannot continue to work.

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

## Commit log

2020-12-07 V01 Update
    Added jumper for USB host config
    Updated crystal caps
    [MicroMod_STM32_Processor.brd, MicroMod_STM32_Processor.sch]
2021-01-28 The 'ol pin switch-a-roo
    - Swapped D0/D1 with PWM0/1 - PWM pins weren't capable of PWM
    - Swapped BATT_VIN with STAT - BATT_VIN needs to be on an ADC pin
    - Moved PB13 to G10 - Based on testing VBUS needs to be broken out or pulled high for USB HS/FS to work correctly
    - Moved PB12 from jumper to G11 for USB Host ID to match with SAMD51 MM
    - Reorganized G0-G6 for better routing
    [MicroMod_STM32_Processor.brd, MicroMod_STM32_Processor.sch]
2021-02-01 V10 design review changes
    Removed battery and 3.3V_EN connections to MicroMod
    [MicroMod_STM32_Processor.brd, MicroMod_STM32_Processor.sch]
2021-02-02 Double-check changes
    - Added VDD range
    - Updated 0.1uF cap footprints from 0402 to 0402_TIGHT
    [MicroMod_STM32_Processor.brd, MicroMod_STM32_Processor.sch]
2021-02-02 Added production panel
    [MicroMod_STM32_Processor-Panel.GBL, MicroMod_STM32_Processor-Panel.GBO, MicroMod_STM32_Processor-Panel.GBP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]
2021-02-03 Updated Panel
    [MicroMod_STM32_Processor-Panel.GBL, MicroMod_STM32_Processor-Panel.GBO, MicroMod_STM32_Processor-Panel.GBP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]
2021-03-29 Updated BOM
    Replaced 22 ohm resistors with 0 ohm
    [MicroMod_STM32_Processor.brd, MicroMod_STM32_Processor.sch]
2021-04-12 Updated USB Load resistors
    Replaced 0 ohm resistors with 22 ohm
    [MicroMod_STM32_Processor.brd, MicroMod_STM32_Processor.sch]
2022-09-27 Swap USART2 for USART1, connect USART2 to ground.
    Also renamed COPI/CIPO to POCI/PICO to match new naming conventions.
    [MicroMod_STM32_Processor.brd, MicroMod_STM32_Processor.sch]
2022-09-27 Rerouted board, cleaned up schematic.
    [MicroMod_STM32_Processor.brd, MicroMod_STM32_Processor.sch]
2022-09-27 Move some vias, replace STM32 with library part.
    [MicroMod_STM32_Processor.brd, MicroMod_STM32_Processor.sch]
2022-09-29 Ready for v11 protos.
    [MicroMod_STM32_Processor-Panel.GBL, MicroMod_STM32_Processor-Panel.GBO, MicroMod_STM32_Processor-Panel.GBP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]
2022-09-30 Update for v20 pushing to reds.
    [MicroMod_STM32_Processor-Panel.GBL, MicroMod_STM32_Processor-Panel.GBO, MicroMod_STM32_Processor-Panel.GBP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]
2022-11-01 Updated from current libraries. Removed R4.
    Reset PUR unneeded per STM32 App Note AN4488.
    [MicroMod_STM32_Processor.brd, MicroMod_STM32_Processor.sch]
2023-01-05 Centered title, re-enabled layers.
    [MicroMod_STM32_Processor.brd, MicroMod_STM32_Processor.sch]

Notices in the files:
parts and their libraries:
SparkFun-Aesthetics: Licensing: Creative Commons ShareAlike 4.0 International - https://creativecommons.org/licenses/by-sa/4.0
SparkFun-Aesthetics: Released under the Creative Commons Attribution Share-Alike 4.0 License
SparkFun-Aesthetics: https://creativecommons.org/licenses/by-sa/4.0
